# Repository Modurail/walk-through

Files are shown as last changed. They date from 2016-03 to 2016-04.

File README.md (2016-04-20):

# walk-through
Operational and wiring schematic for the NGM walk-through module (2016 version).

This project and the associated schematics and libraries are built using [KiCad EDA](http://kicad-pcb.org//).

## Electrical Notes
1) After installation in the layout on April 17, 2016, we discovered that the AC accessory bus only provides 13VAC (actual measurement of 12.96 taken right of the master control box.) Our initial resistor values were based on the assumption that the bus provided 18VAC.

2) The initial resistor value was set at 47 ohms. Measured voltage at the coil was less than 10 VAC, which is lower than the specified operational voltage of 10.1VAC.

3) The coil seemed to operate well enough without a dropping resistor. However, the measured voltage at the coil without a resistor was about 12.8VAC. After some experimenting, we ended up with two 15 ohm resistors in parallel that measured 7.9 ohms. These were 10 watt resistors which should give enough power dissipation for dropping less than 2 volts to the coil. The measured voltage at the coil with this setup was 11.8VAC, well within the acceptable voltage range.

4) The schematic was updated on April 20, 2016 to reflect this change in the resistor values.

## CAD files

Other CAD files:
2016 Walk Through Wiring.skp

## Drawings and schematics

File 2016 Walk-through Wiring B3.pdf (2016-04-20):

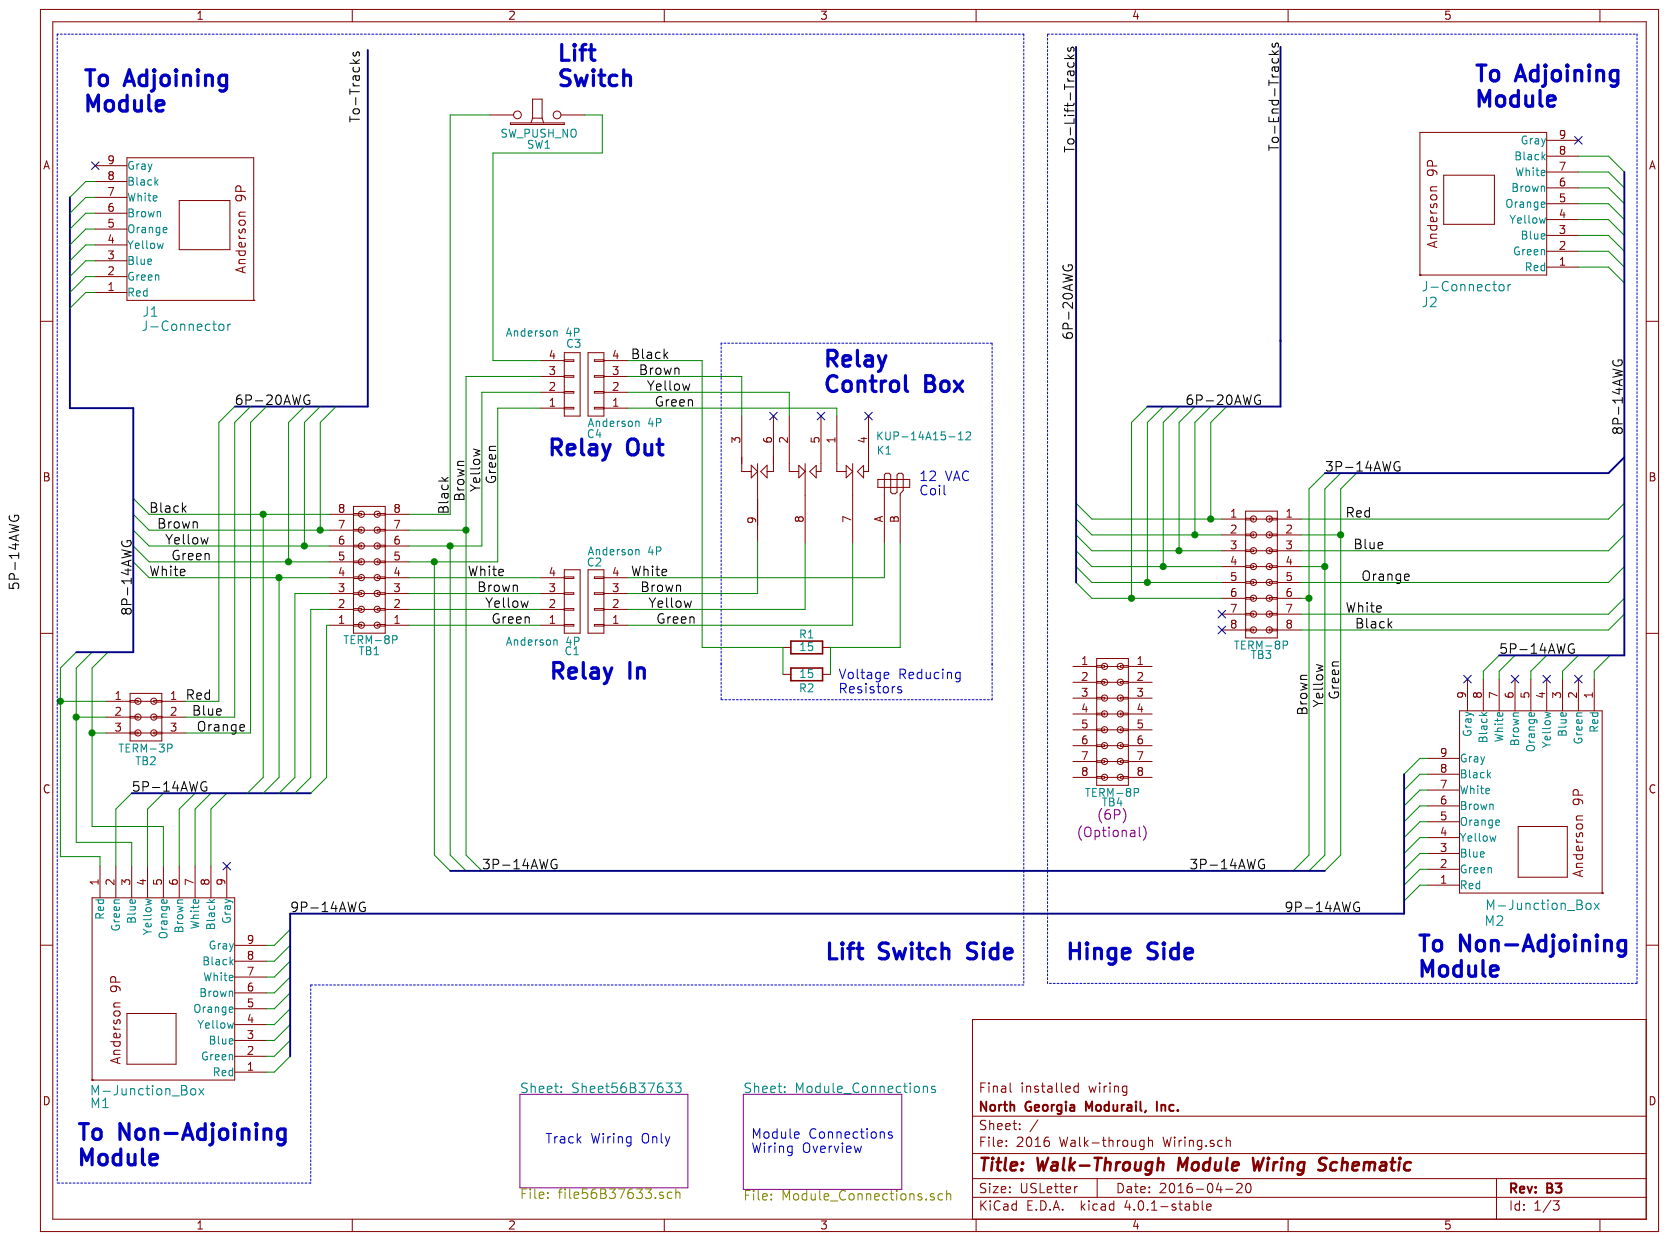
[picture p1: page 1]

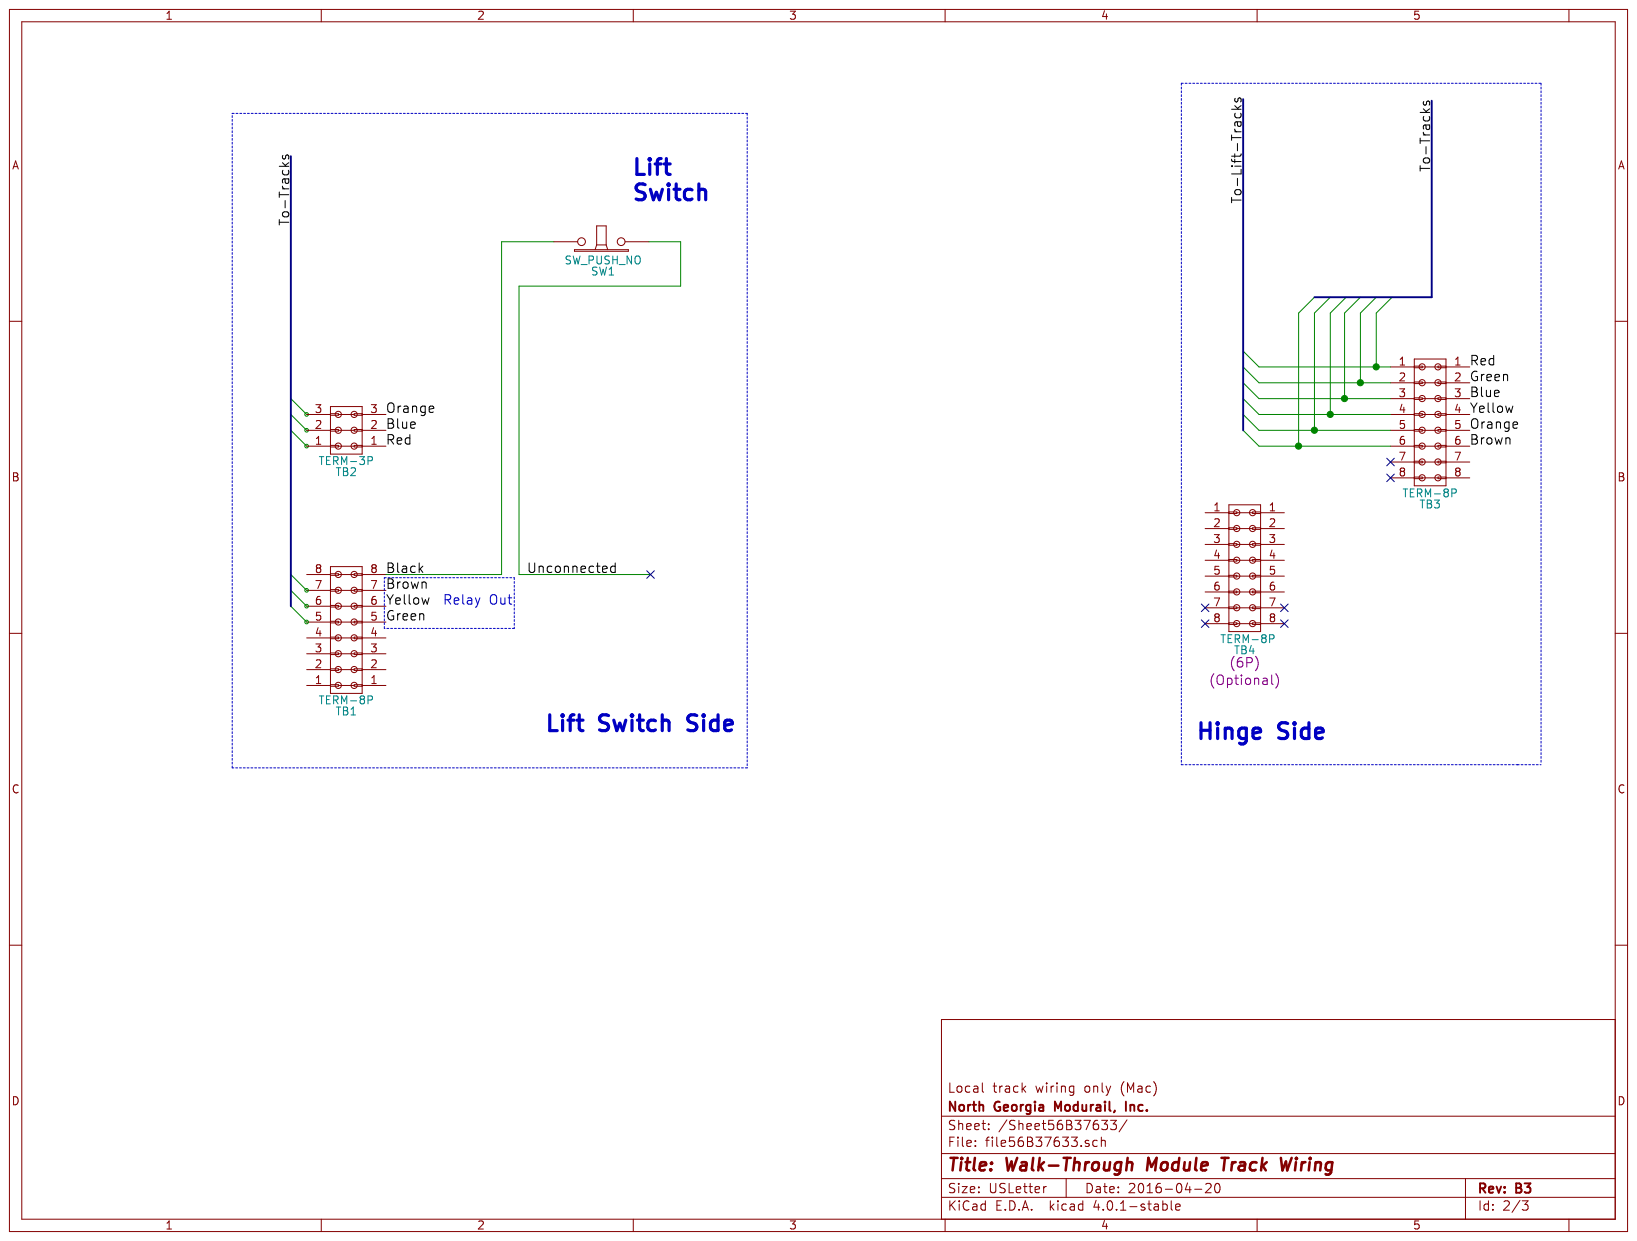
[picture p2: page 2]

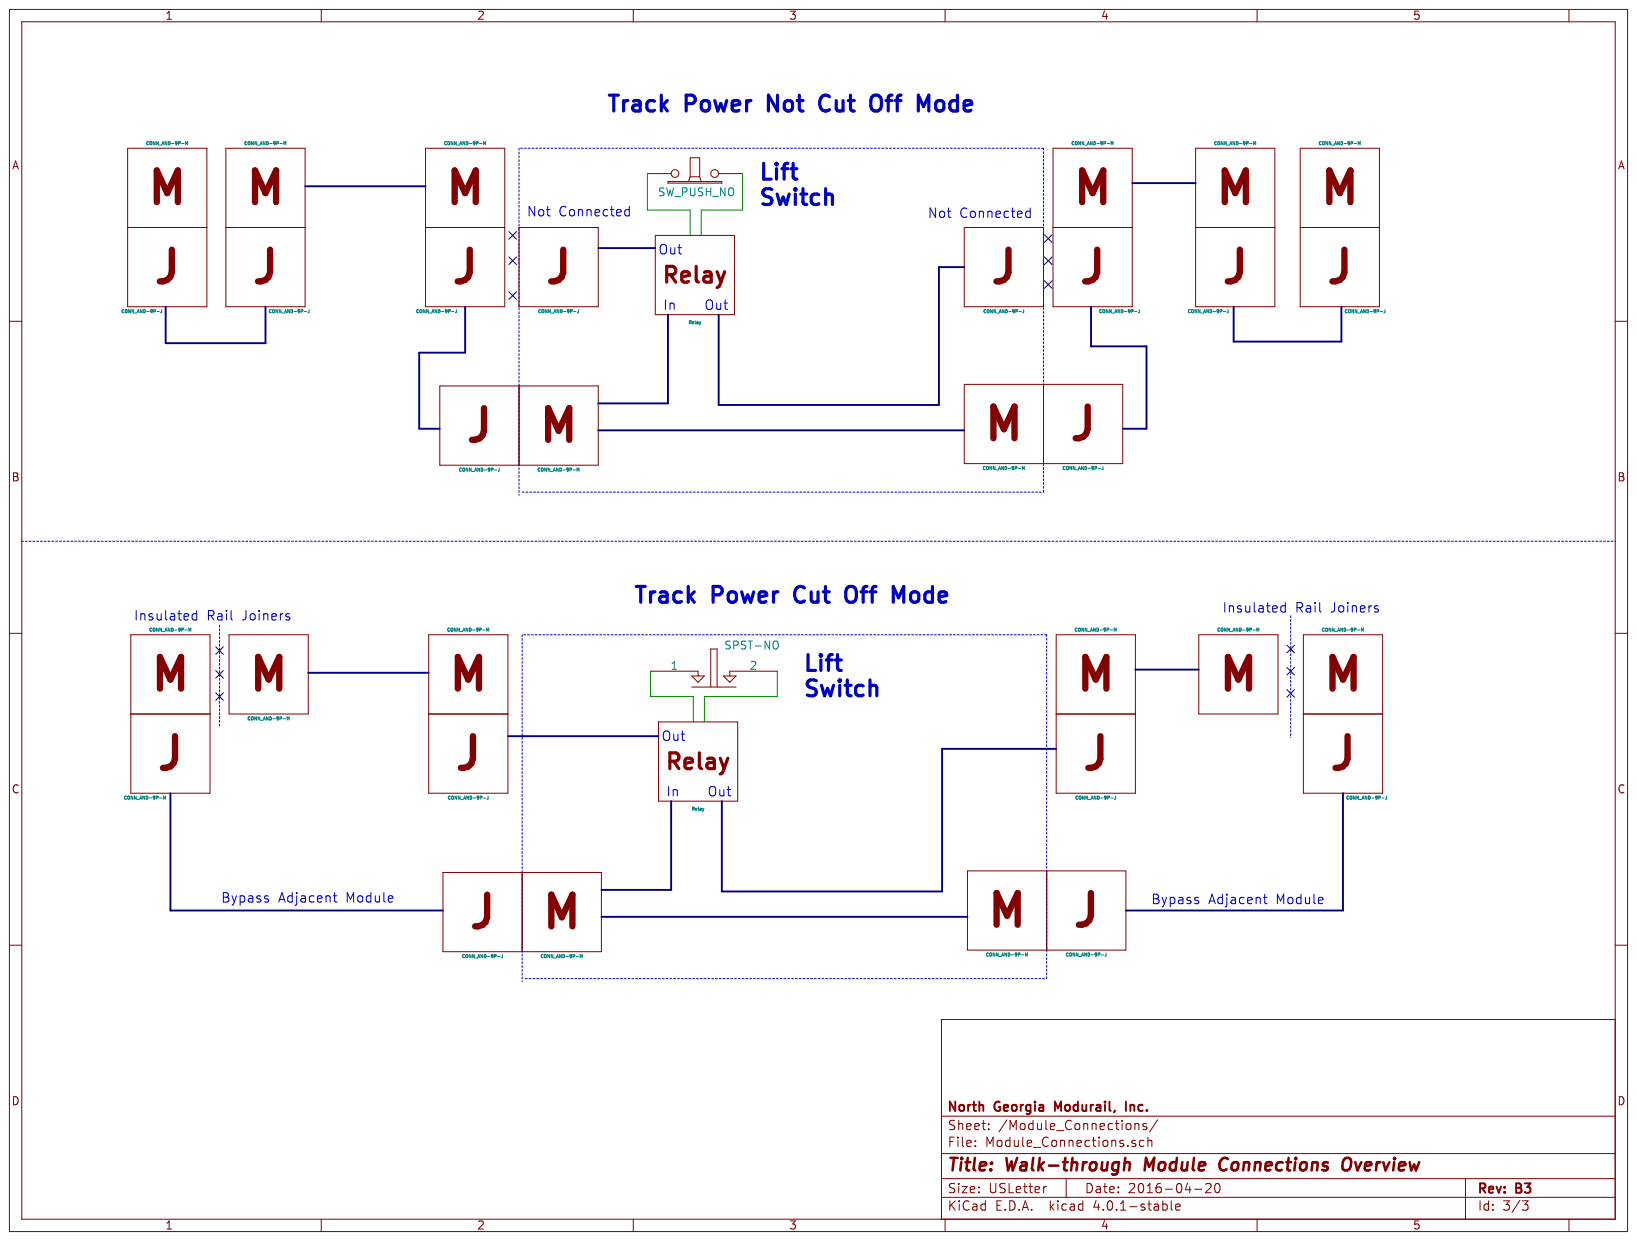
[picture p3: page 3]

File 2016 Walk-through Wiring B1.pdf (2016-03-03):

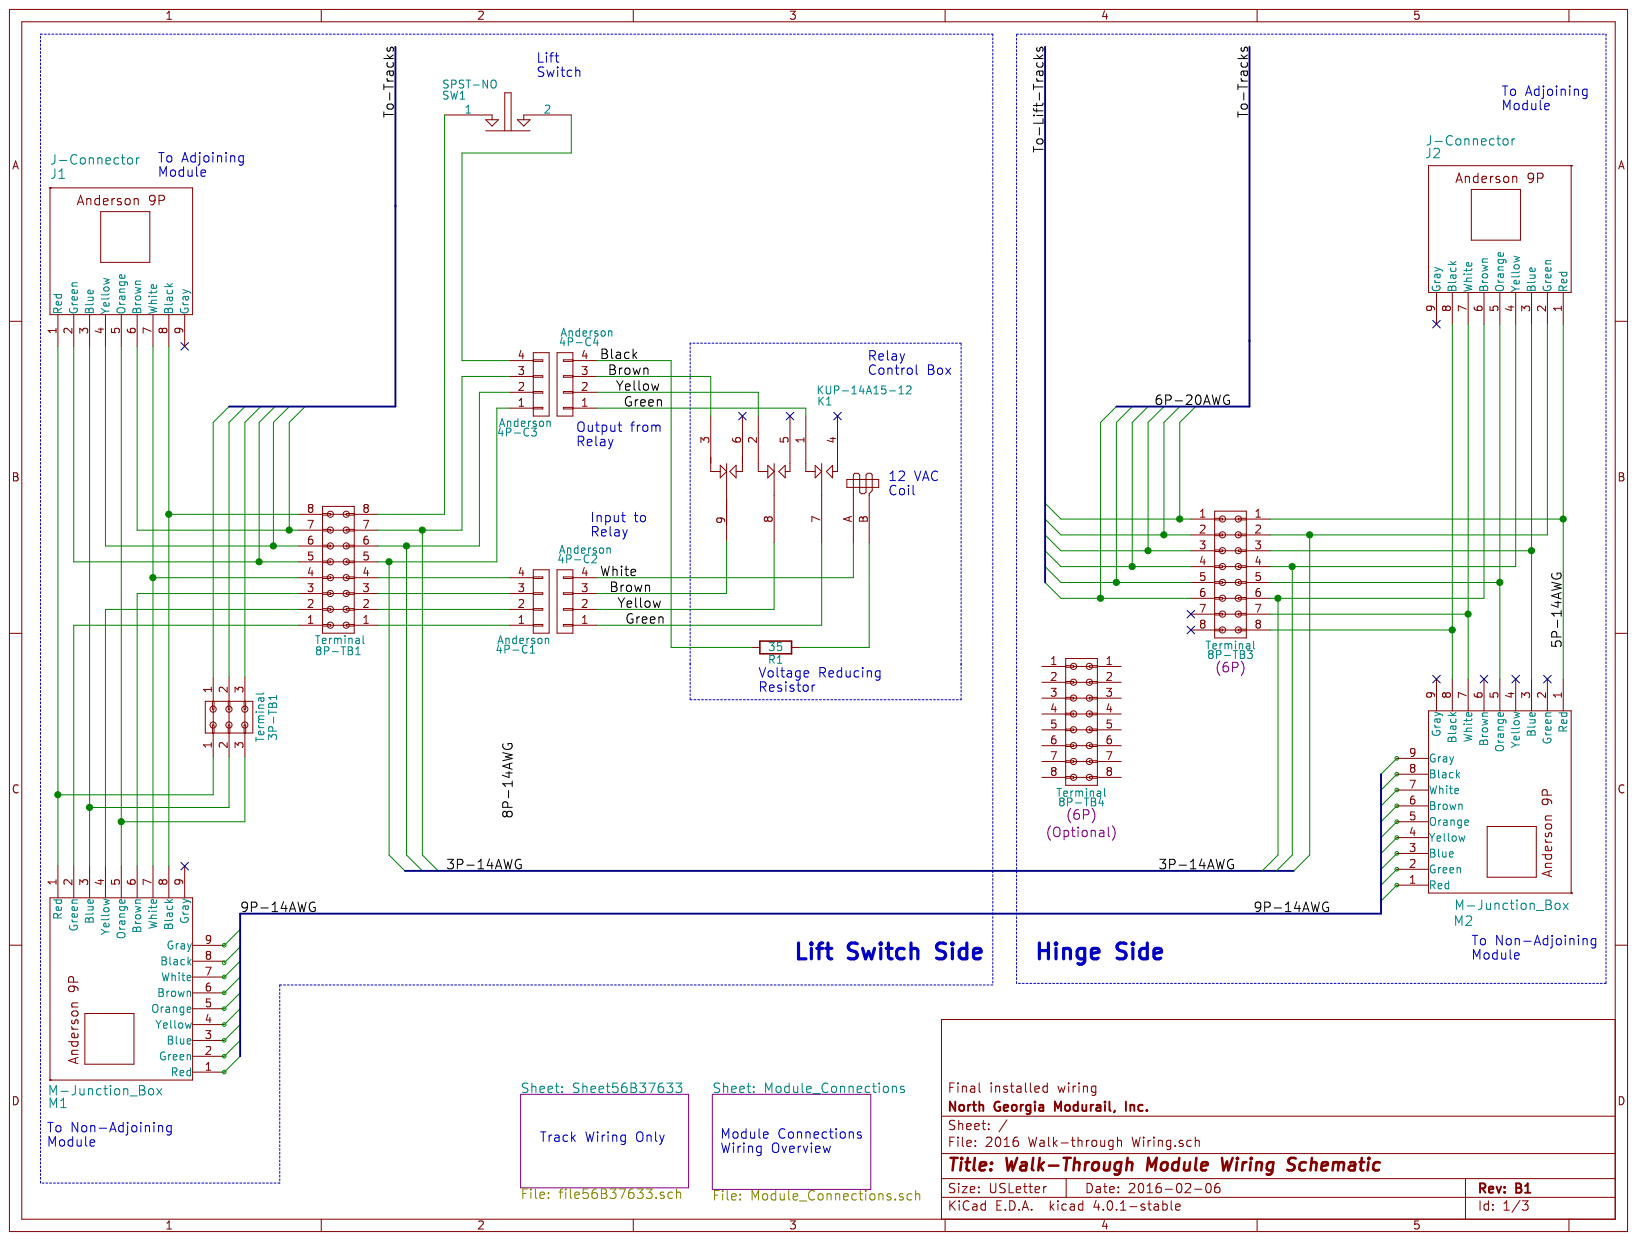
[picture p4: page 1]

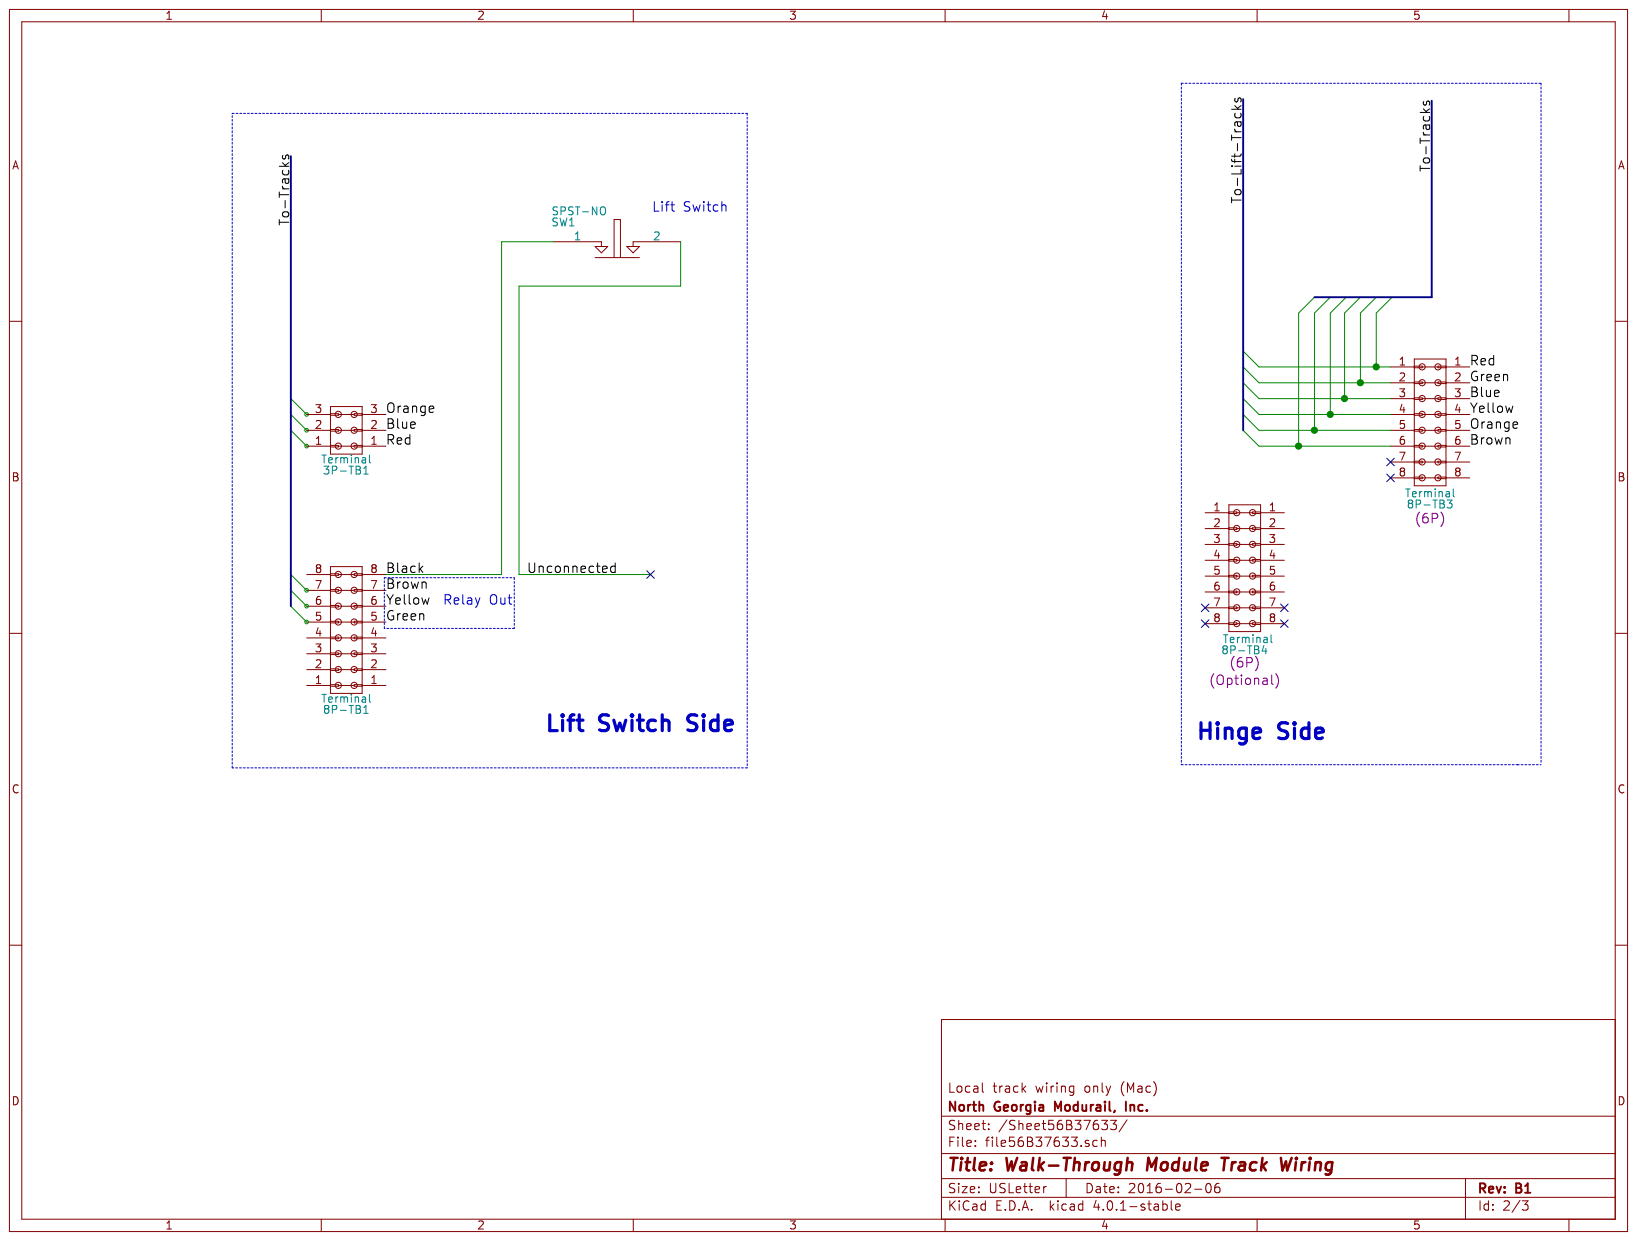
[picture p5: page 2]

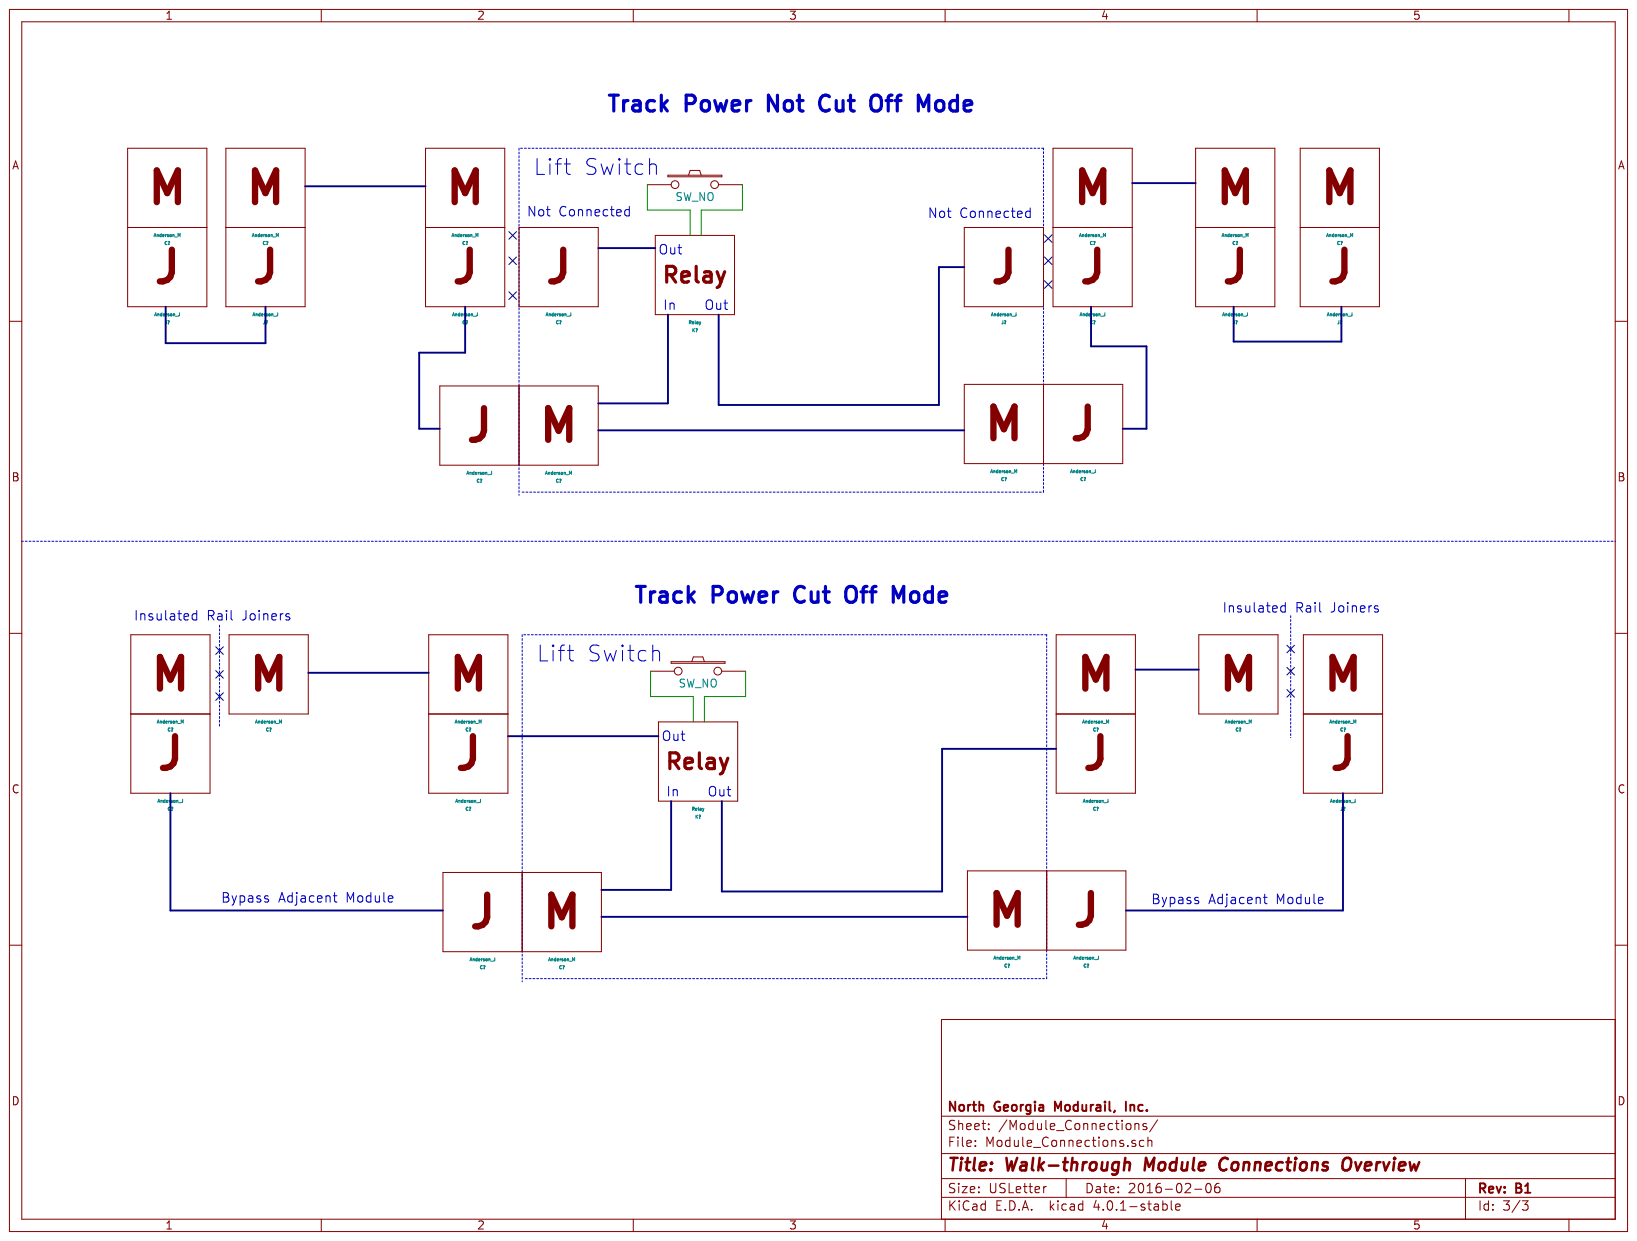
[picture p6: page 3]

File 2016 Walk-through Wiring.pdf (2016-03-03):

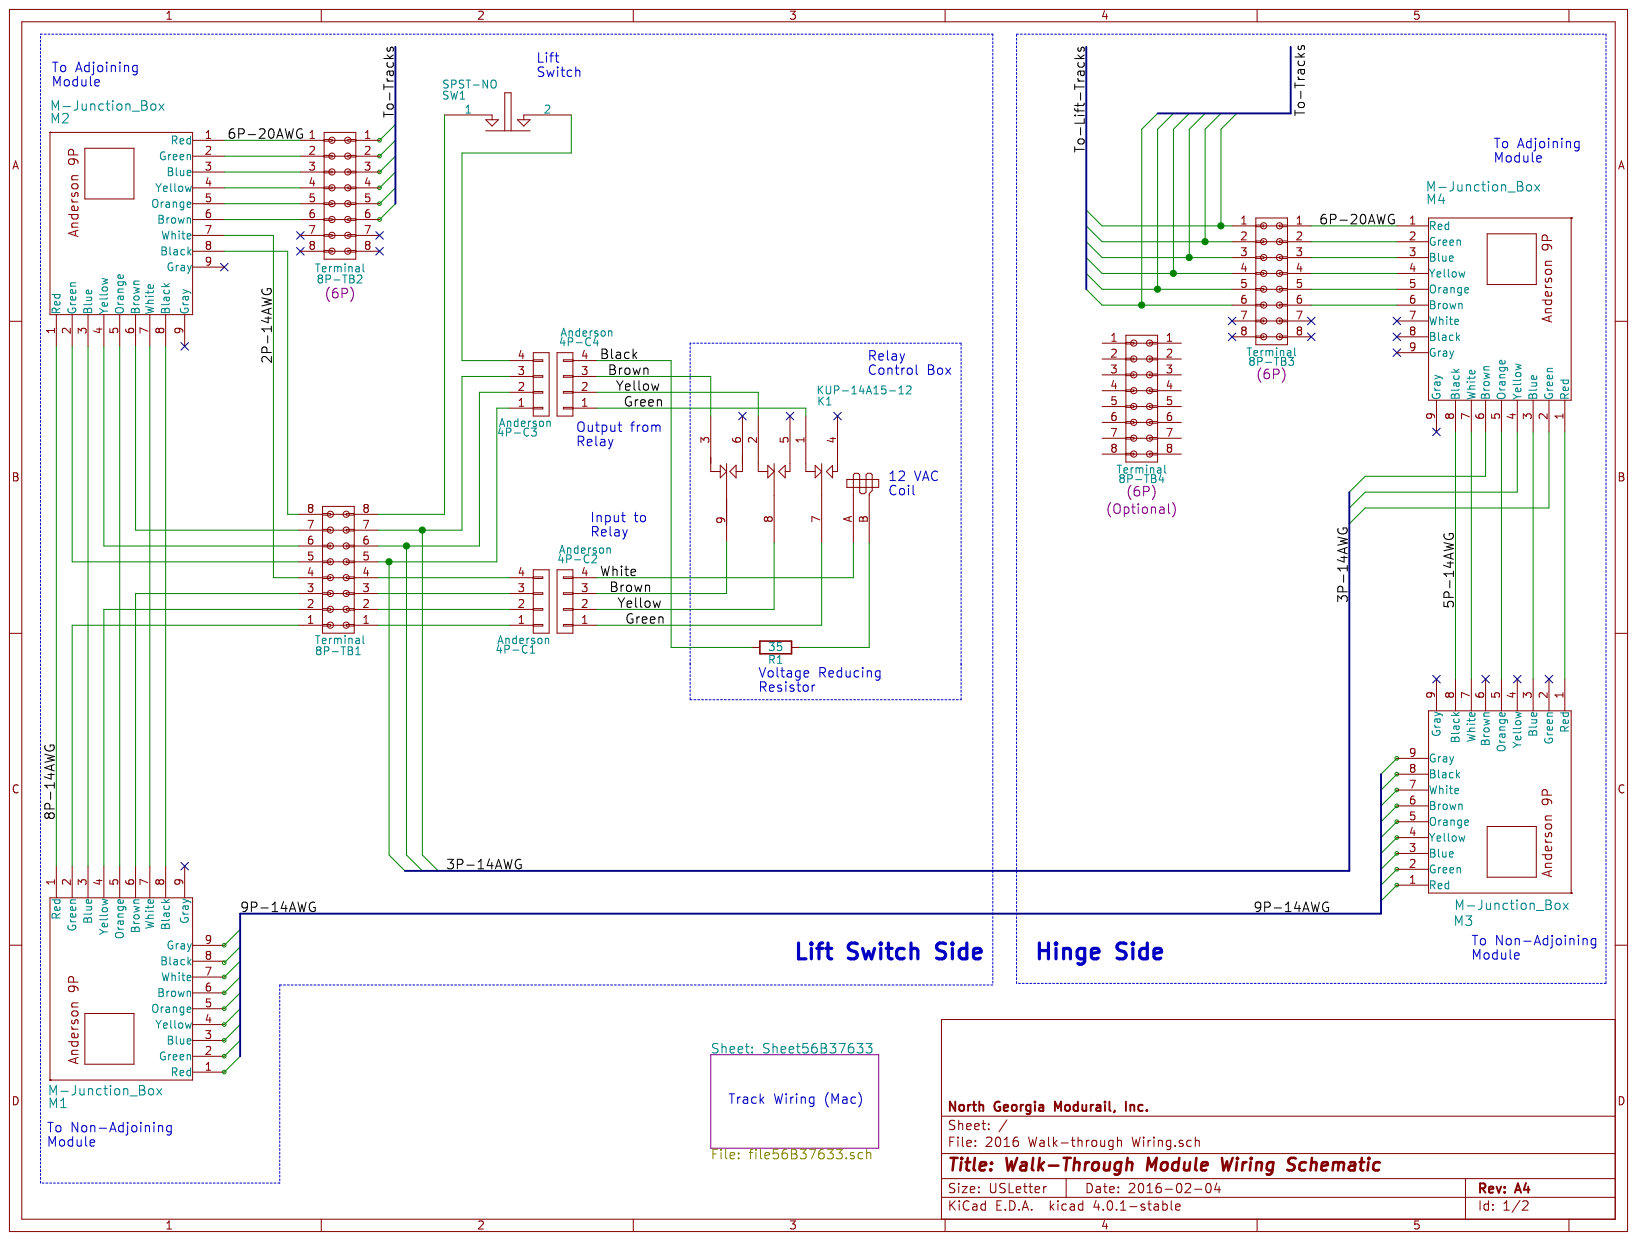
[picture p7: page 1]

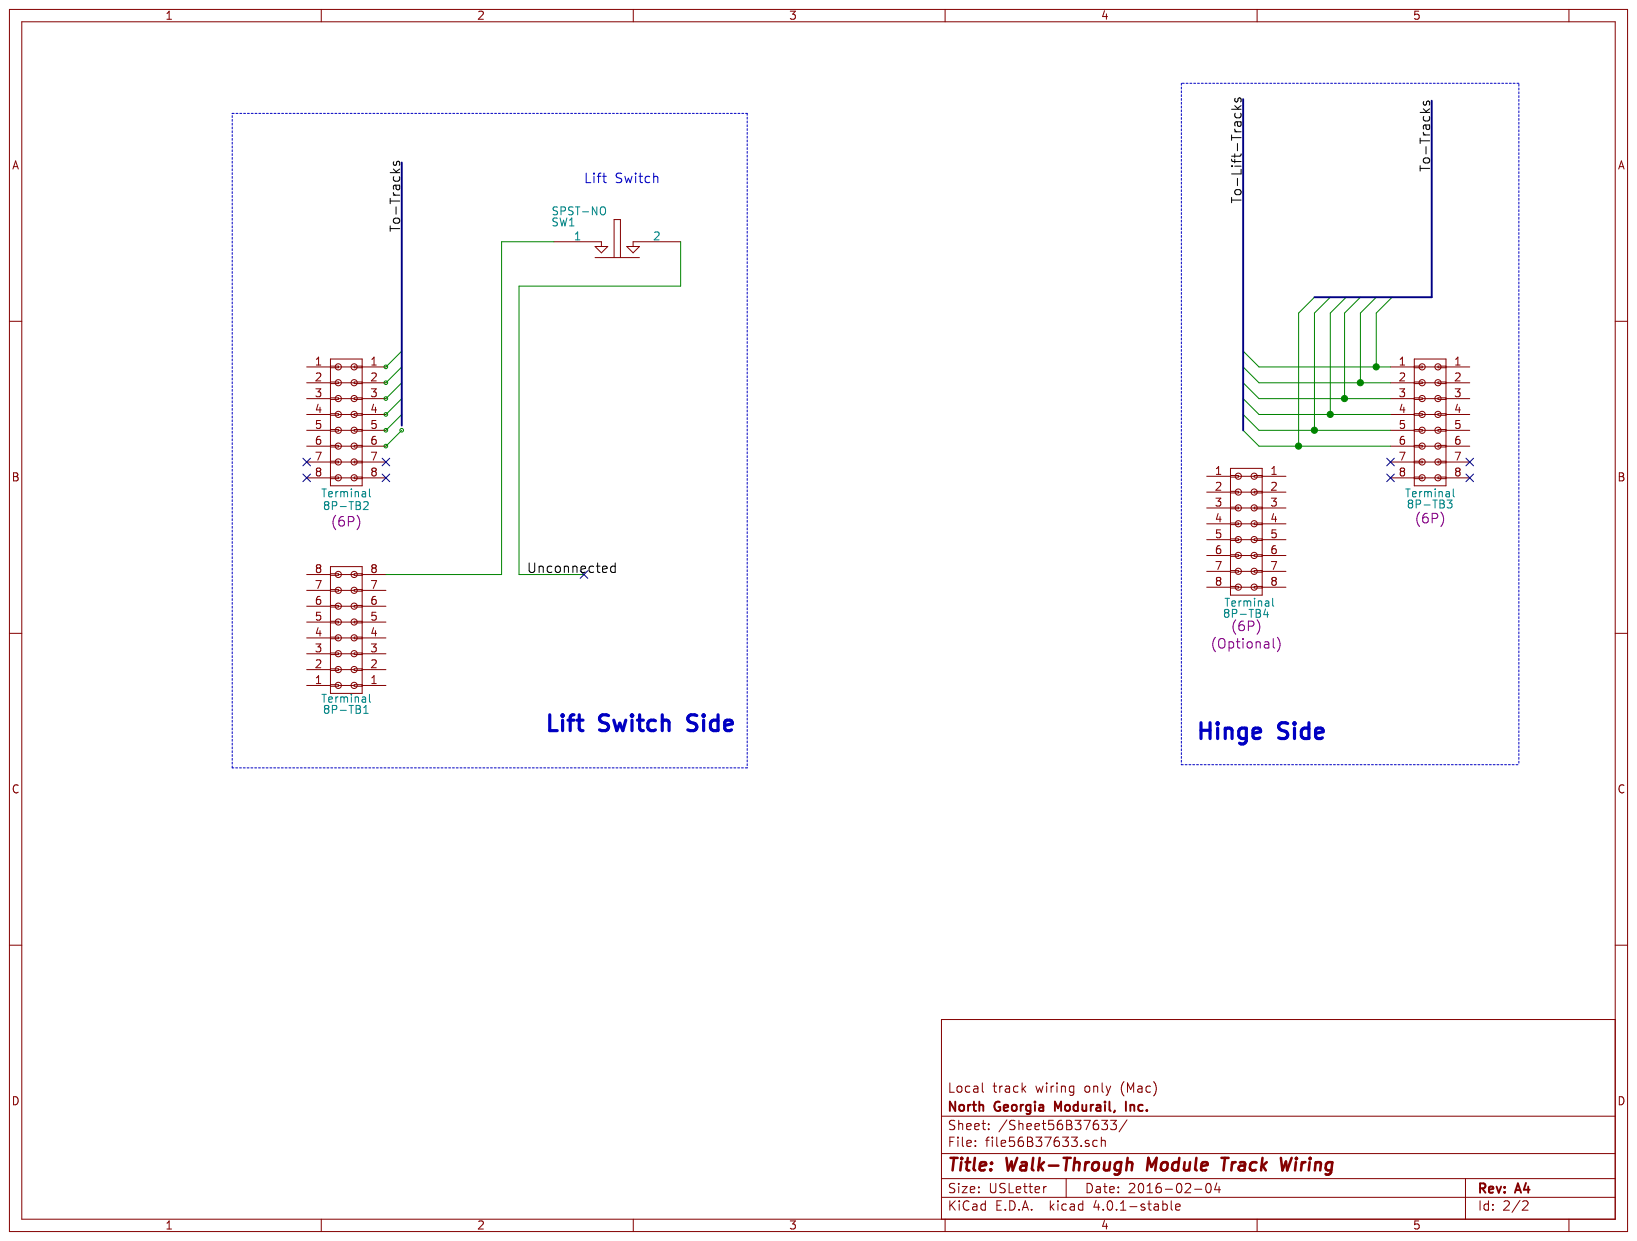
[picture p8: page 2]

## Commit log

2016-03-03 Initial upload of project files
    Moving all Kicad project files from local PC to GitHub repo.
    [2016 Walk-through Wiring.kicad_pcb, 2016 Walk-through Wiring.sch, Master Wiring.sch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]
2016-03-03 Added link to KiCad EDA
    Updating the README.md file.
2016-04-20 Updated schematic to version B3
    Corrected R1 and R2 values and cleaned up the schematic to make it
    easier to read.
    [2016 Walk Through Wiring.skp]
